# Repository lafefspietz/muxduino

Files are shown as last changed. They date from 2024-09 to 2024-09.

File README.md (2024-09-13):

# muxduino

## Arduino Shield multiplexer for audio interface to organic circuits.

This is a platform for discovering neuron-like elements in an arbitrary network of electrodes. 8 relays connect to the input side and 8 relays connect to the output side. This set of relays allows for 256x256 = 65,536 possible ways to connect the signals.  If we assume that there are neuron-like responses to be found in some combination of signal paths, we can hunt for these using software.  Algorithms can be developed to hunt for neuron-like behavior and can be improved over time.  

## [muxduino.html](muxduino.html)

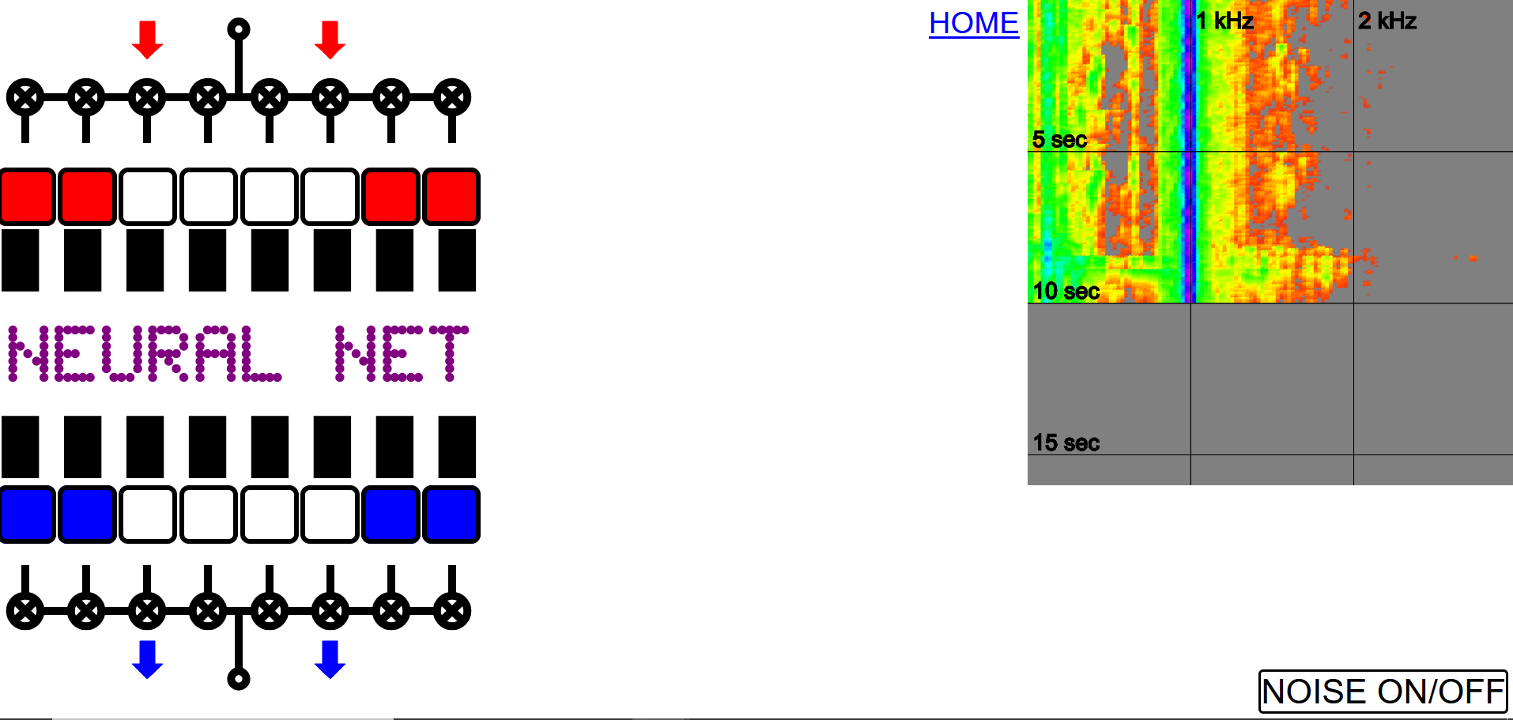
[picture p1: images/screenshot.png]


## [muxduino.py](muxduino.py)

## [arduino/muxduino/muxduino.ino](arduino/muxduino/muxduino.ino)

## [geometron/](geometron/)

## [webeditor.html](webeditor.html)

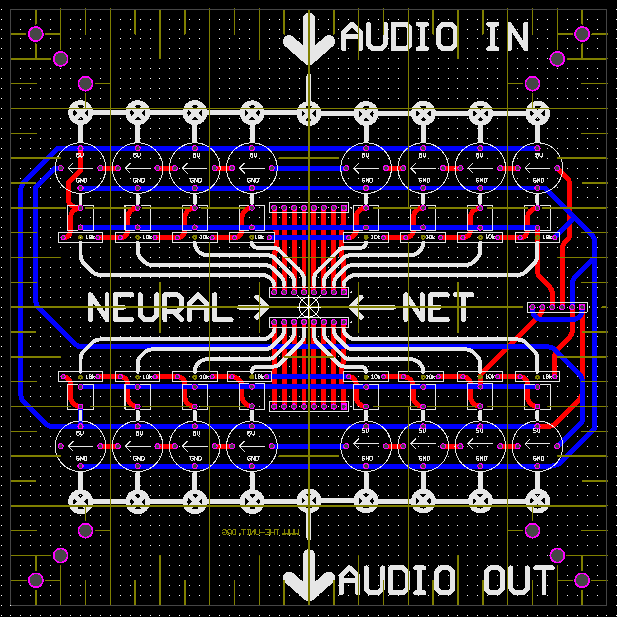
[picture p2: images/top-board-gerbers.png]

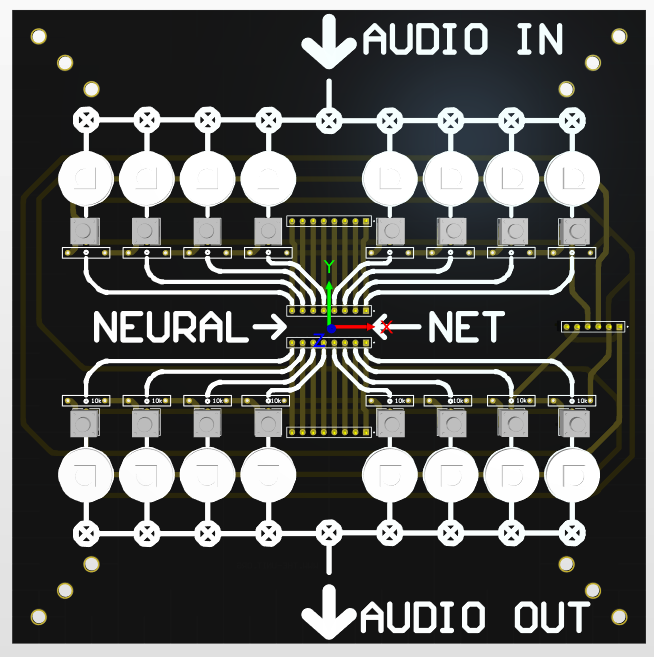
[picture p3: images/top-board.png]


 - [pcb/top-board-gerbers.zip](pcb/top-board-gerbers.zip)

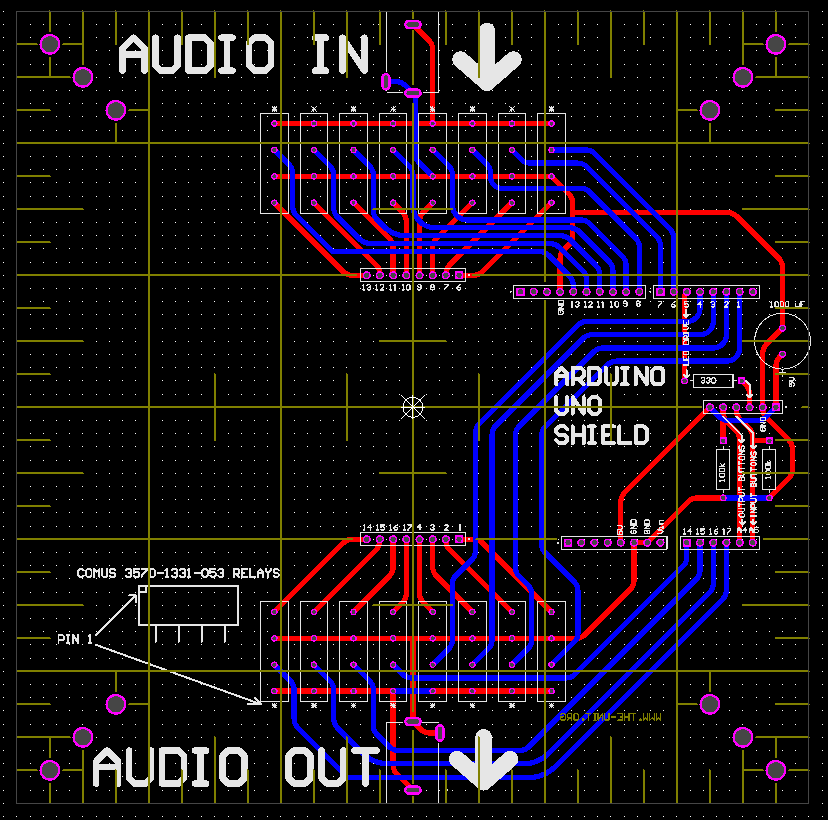
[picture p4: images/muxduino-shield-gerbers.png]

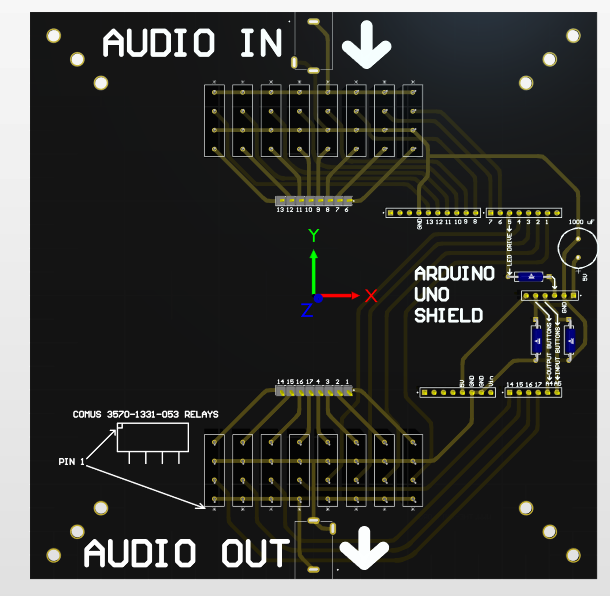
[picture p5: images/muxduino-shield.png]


 - [pcb/muxduino-shield-gerbers.zip](pcb/muxduino-shield-gerbers.zip)

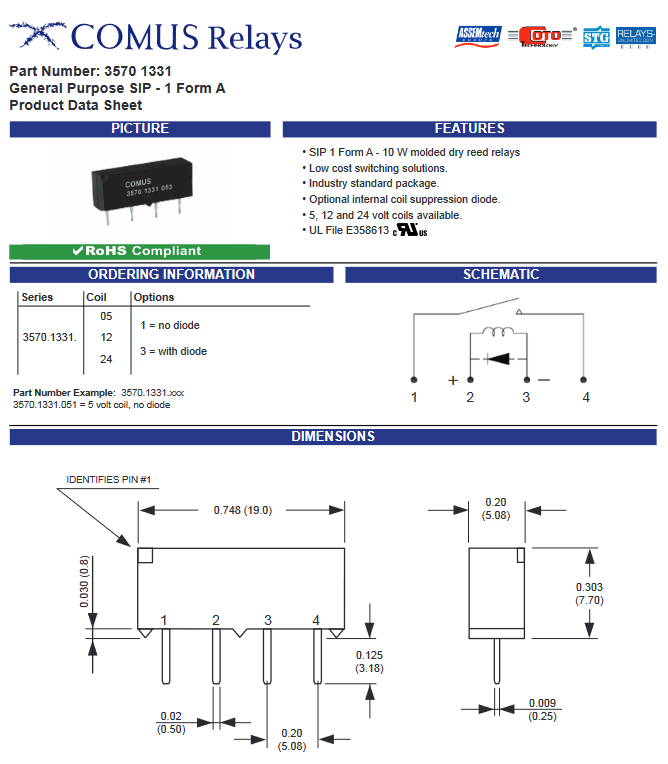
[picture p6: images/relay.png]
(https://www.digikey.com/en/products/detail/comus-international/3570-1331-053/7497099)


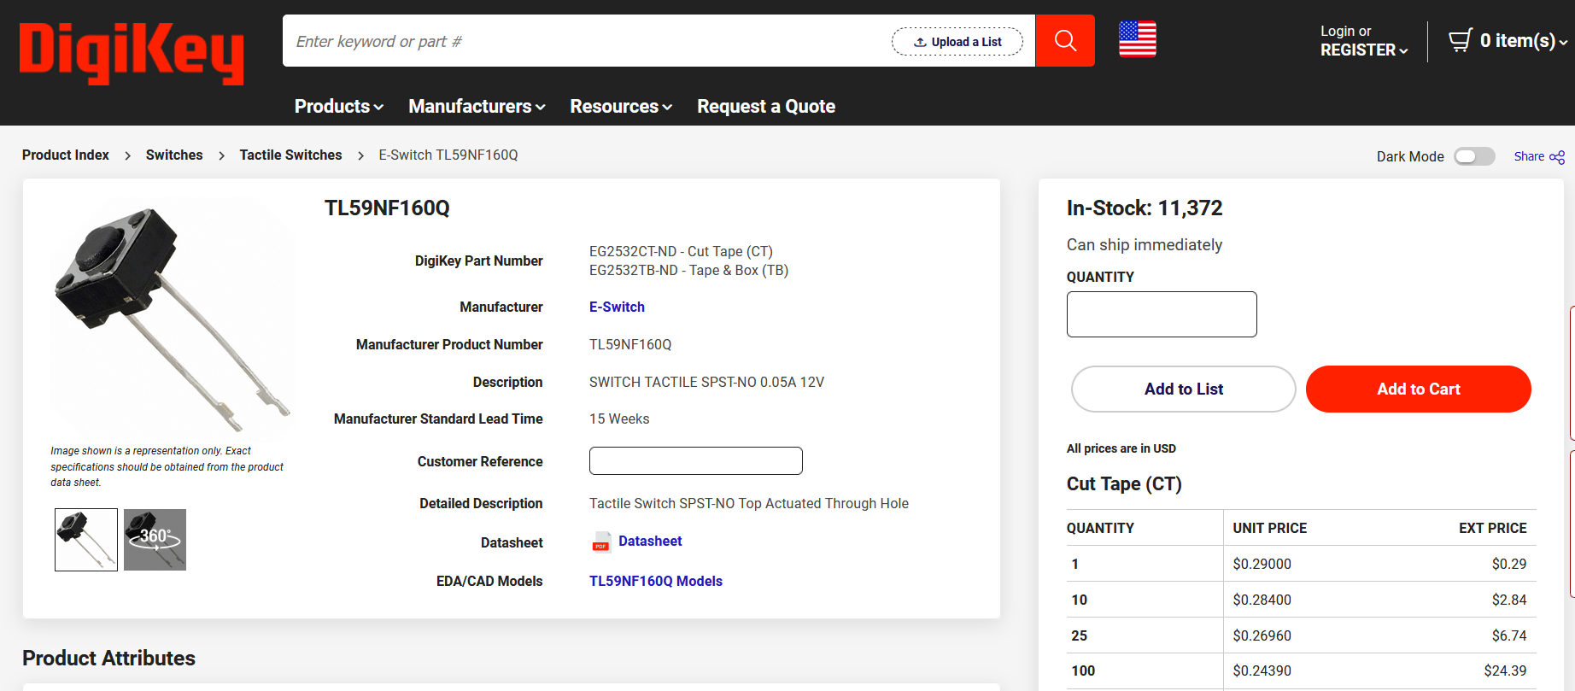
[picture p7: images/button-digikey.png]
(https://www.digikey.com/en/products/detail/e-switch/TL59NF160Q/390533)


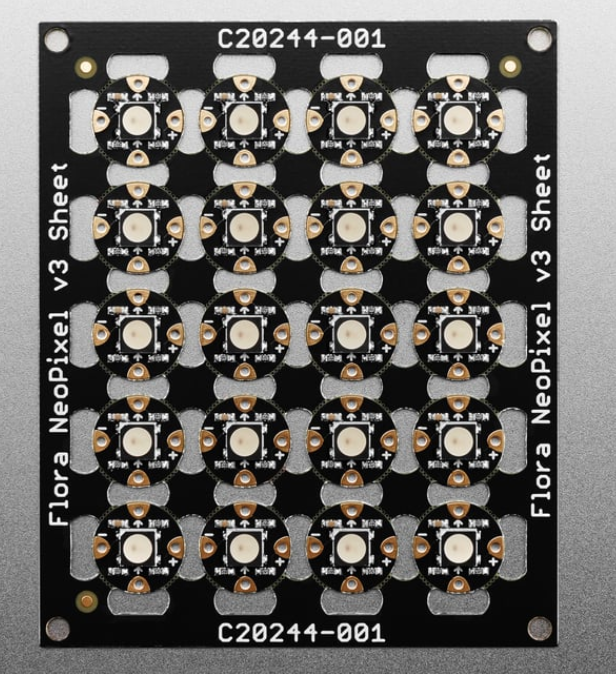
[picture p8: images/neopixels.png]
(https://www.adafruit.com/product/1559)


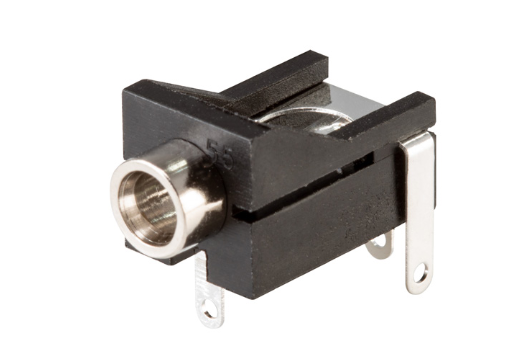
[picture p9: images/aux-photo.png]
(https://www.digikey.com/en/products/detail/cui-devices/MJ-3536N/281264)


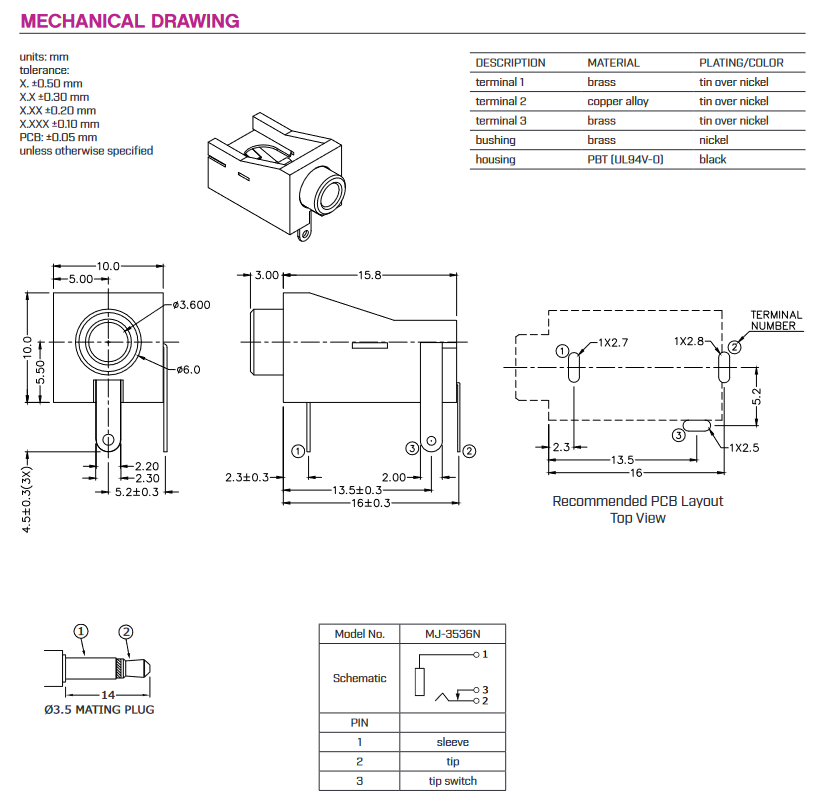
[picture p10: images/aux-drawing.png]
(https://www.digikey.com/en/products/detail/cui-devices/MJ-3536N/281264)


# Bill of Materials

 - [Comus 3570-1331-053 relay](https://www.digikey.com/en/products/detail/comus-international/3570-1331-053/7497099)
 - [Cui Devices MJ-3536N Board Mount 1/8" Audio Connector](https://www.digikey.com/en/products/detail/cui-devices/MJ-3536N/281264)
 - [E-Switch TL59NF160Q Button](https://www.digikey.com/en/products/detail/e-switch/TL59NF160Q/390533)
 - [Flora RGB Smart NeoPixel version 3 - Sheet of 20](https://www.adafruit.com/product/1559)
 - [330 ohm resistor](https://www.digikey.com/en/products/detail/stackpole-electronics-inc/CF18JT330R/1741683)
 - [100k resistor](https://www.digikey.com/en/products/detail/stackpole-electronics-inc/RNF14FTD100K/1706591)
 - [10k resistor](https://www.digikey.com/en/products/detail/yageo/MFR-25FBF52-10K/13219)
 - [1000 uF capacitor](https://www.digikey.com/en/products/detail/rubycon/16PK1000MEFC10X12-5/3563556)
 - [0.1 inch male headers](https://www.digikey.com/en/products/detail/amphenol-cs-commercial-products/G800W268018EU/17083164)
 - [6 and 8 pin socket headers](https://www.amazon.com/Didamx-120Pcs-2-54MM-Stackable-arduino/dp/B074GQ9LKY/)
 - [16 pin DIP sockets](https://www.amazon.com/uxcell-Pieces-2-54mm-Double-Adapter/dp/B00O9YPVAM/)

# CAD Files

## Libraries

 - [pcb/SchlibLafe.SchLib](pcb/SchlibLafe.SchLib)
 - [pcb/PcbLibLafe.PcbLib](pcb/PcbLibLafe.PcbLib)

## muxduino-shield

 - [pcb/muxduino-shield/muxduino-shield.PcbDoc](pcb/muxduino-shield/muxduino-shield.PcbDoc)
 - [pcb/muxduino-shield/muxduino-shield.PrjPcb](pcb/muxduino-shield/muxduino-shield.PrjPcb)
 - [pcb/muxduino-shield/muxduino-shield.PrjPcbStructure](pcb/muxduino-shield/muxduino-shield.PrjPcbStructure)
 - [pcb/muxduino-shield/muxduino-shield.SchDoc](pcb/muxduino-shield/muxduino-shield.SchDoc)
 - [pcb/muxduino-shield/muxduino-shield.step](pcb/muxduino-shield/muxduino-shield.step)

## top-board

 - [pcb/top-board/top-board.PcbDoc](pcb/top-board/top-board.PcbDoc)
 - [pcb/top-board/top-board.PrjPcb](pcb/top-board/top-board.PrjPcb)
 - [pcb/top-board/top-board.PrjPcbStructure](pcb/top-board/top-board.PrjPcbStructure)
 - [pcb/top-board/top-board.SchDoc](pcb/top-board/top-board.SchDoc)
 - [pcb/top-board/top-board.step](pcb/top-board/top-board.step)

## Switch state

The switch state is represented by an integer from 0 to 2^16-1 = 65535. This is a 16 bit number. We divide it into two bytes, the 8 bit input state and the 8 bit output state.  

## Jupyter Notebook in specific local folder

```
jupyter notebook --notebook-dir=c:\xampp\htdocs 
```

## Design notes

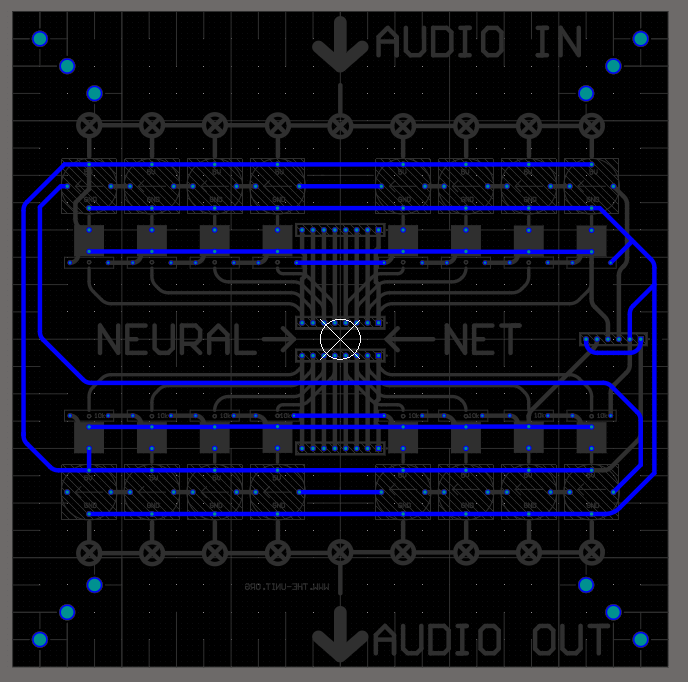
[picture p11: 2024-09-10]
images/top-board-bottom-copper.png

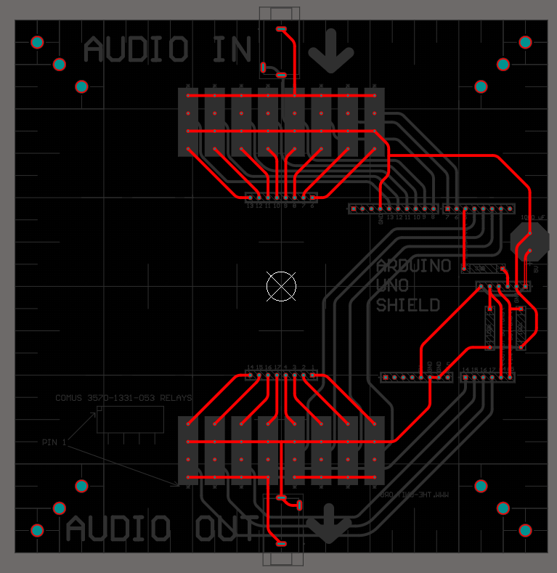
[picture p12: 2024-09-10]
images/muxduino-shield-copper.png

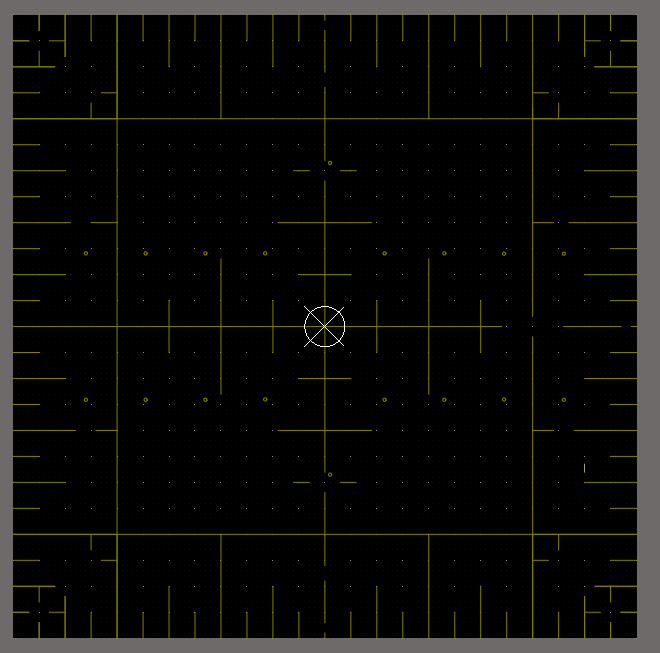
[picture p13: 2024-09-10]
images/top-board-bottom.png

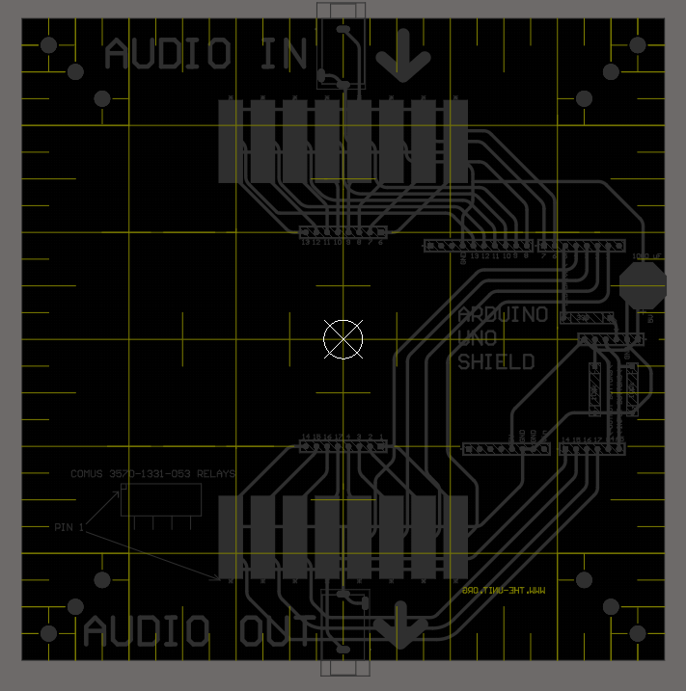
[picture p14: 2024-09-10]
images/muxduino-shield-silkscreen-bottom.png

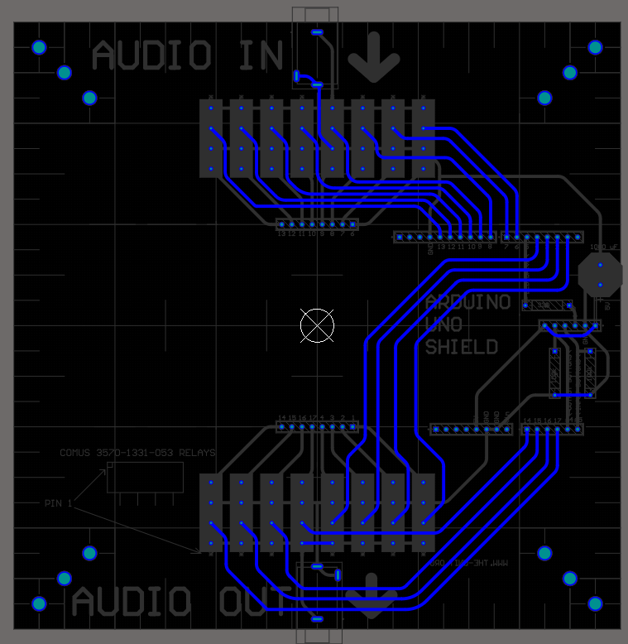
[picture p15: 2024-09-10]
images/muxduino-shield-copper-bottom.png

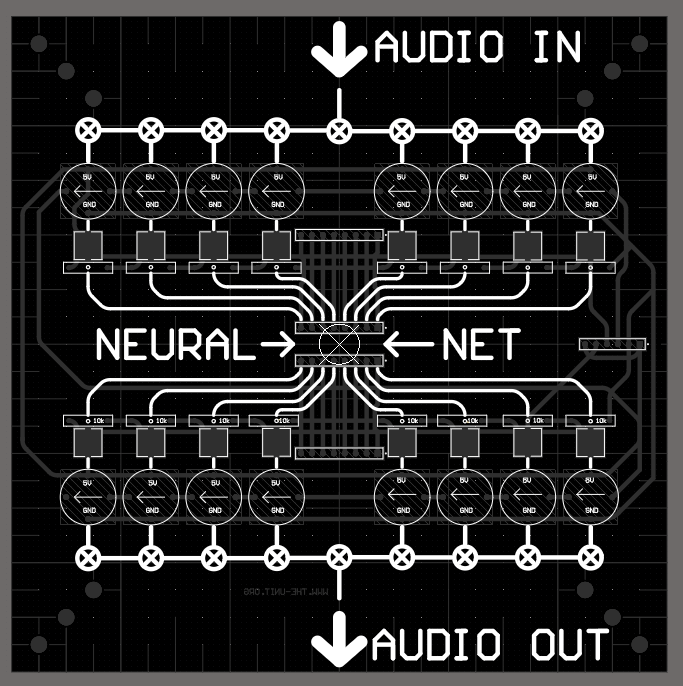
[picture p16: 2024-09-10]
images/top-board-silkscreen.png

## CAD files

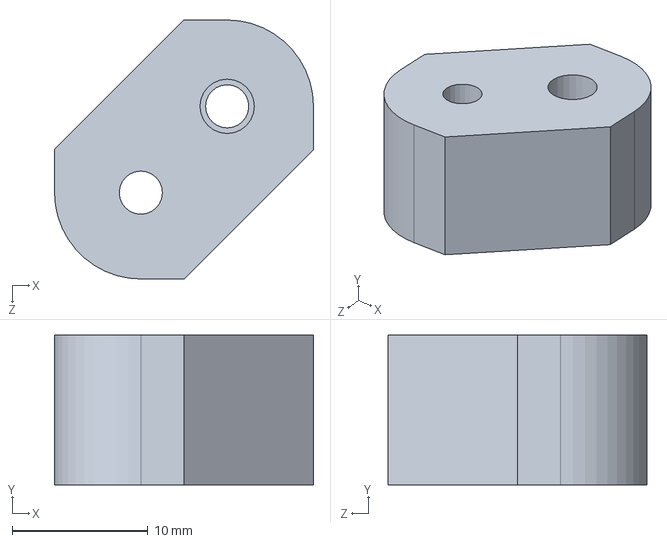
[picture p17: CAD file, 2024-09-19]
3dprint/mounting-bracket.SLDPRT
19.1 x 11.0 x 19.1 mm

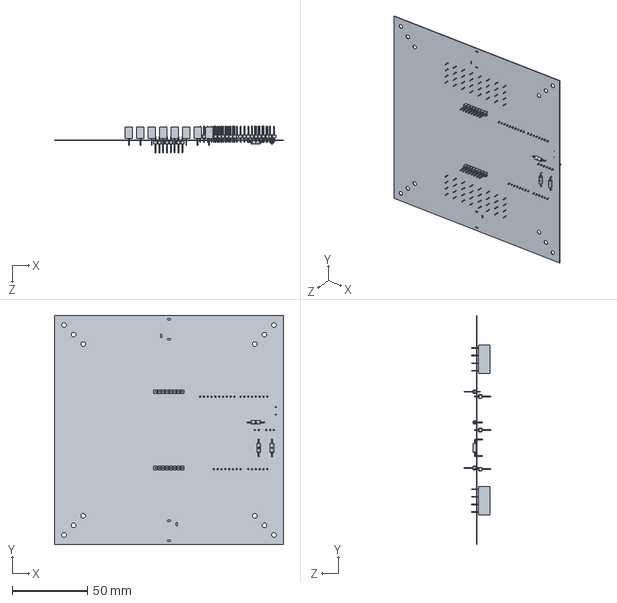
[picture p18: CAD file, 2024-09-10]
mechanical/muxduino-shield.SLDPRT
152.4 x 152.4 x 18.0 mm

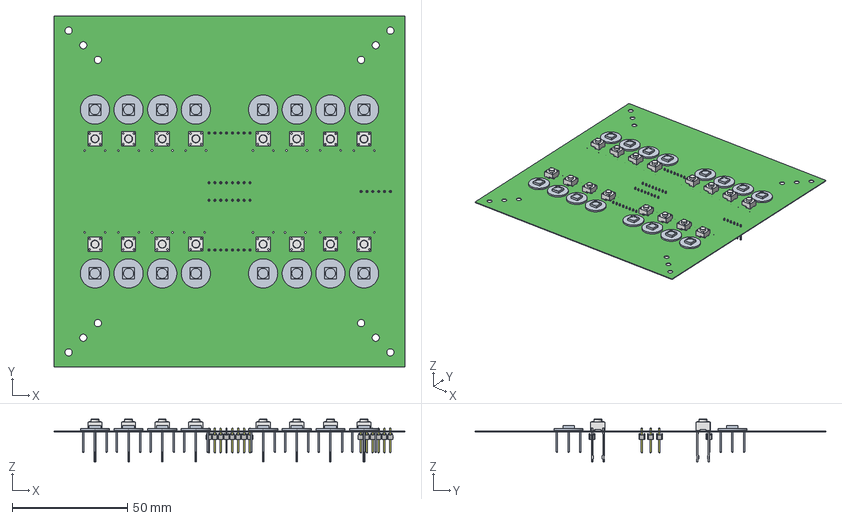
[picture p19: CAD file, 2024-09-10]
pcb/top-board/top-board.step
152.4 x 152.4 x 18.6 mm
TSW-108-07-G-S_body x 4
T-1S6-07-TSW-1-07-8-S x 4
TL59AF100Q x 16
half-inch-round-neopixel-board x 16
TSW-106-07-G-S_body
T-1S6-07-TSW-1-07-6-S

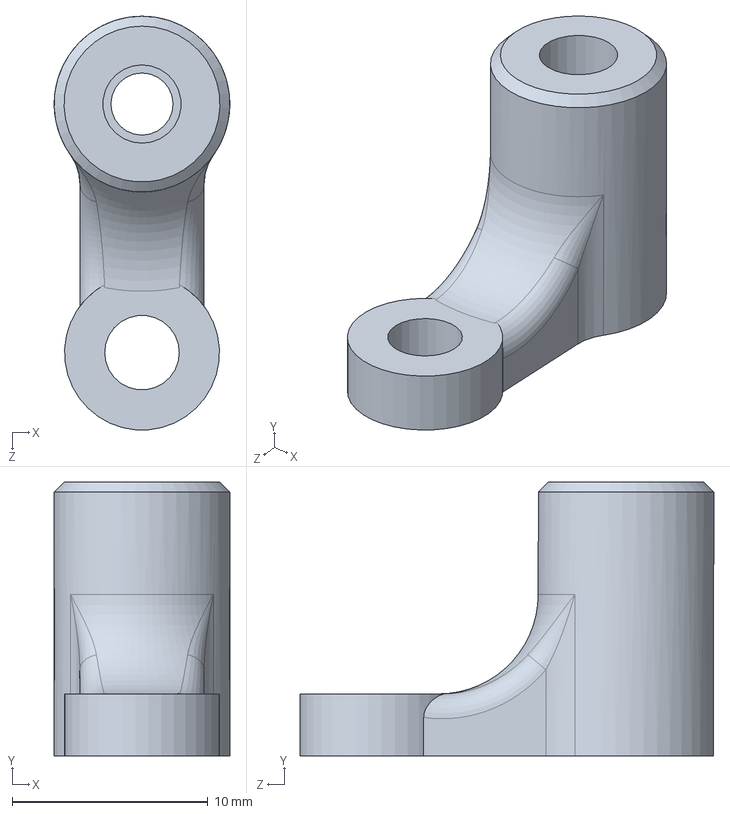
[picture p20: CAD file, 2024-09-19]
3dprint/edgebracket.SLDPRT
8.97 x 14.0 x 21.1 mm

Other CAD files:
pcb/muxduino-shield/muxduino-shield.step
3dprint/edgebracket.STL
3dprint/mounting-bracket.STL

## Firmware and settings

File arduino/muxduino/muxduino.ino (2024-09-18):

/*
*test code for building 16 bit switch controller for muxduino
*
*/

#include <Adafruit_NeoPixel.h>
#ifdef __AVR__
#endif

// Which pin on the Arduino is connected to the NeoPixels?

#define PIN 5 // UNO

// How many NeoPixels are attached to the Arduino?
#define NUMPIXELS 16 // 
//there are 16

// When setting up the NeoPixel library, we tell it how many pixels,  
// and which pin to use to send signals. Note that for older NeoPixel
// strips you might need to change the third parameter -- see the
// strandtest example for more information on possible values.
Adafruit_NeoPixel pixels(NUMPIXELS, PIN, NEO_GRB + NEO_KHZ800);


//define bit numbers on the Cryoelec controller and map them to Arduino pins

#define input1 13
#define input2 12
#define input3 11
#define input4 10
#define input5 9
#define input6 8
#define input7 7
#define input8 6

#define output1 17//this set of 4 pins{17,16,15,14} are reversed from what the silk screen says
#define output2 16
#define output3 15
#define output4 14
#define output5 4
#define output6 3
#define output7 2
#define output8 1

int inputbits[8] = {0,0,0,0,0,0,0,0};
int outputbits[8] = {0,0,0,0,0,0,0,0};

int buttonlevels[8] = {1023,823,665,536,424,321,220,114};


int inputbuttons = 0;// variable which reads out the analog input from the button ladder
int outputbuttons = 0;// variable which reads out the analog input from the button ladder
int inputbuttonsprev = 0;
int outputbuttonsprev = 0;

int delta = 20;//the acceptable difference between an analog value and an expected button state value
int mode = 1;//modes are 1,2,3,4,5,6 which are pixel 5,4,3,2,1, and 0 respectively, mode 0 is off, mode -1 is color cycle with all switches off
int cycle = 0;//variable for cycling colors as test pattern with switch off

int switchstate = 0;
String inString = "";  // string to hold input

void setup() {
    Serial.begin(9600);//set the baud rate to 9600 baud.

    //Set all bits to digital output mode:

    pinMode(input1,OUTPUT);
    pinMode(input2,OUTPUT);
    pinMode(input3,OUTPUT);
    pinMode(input4,OUTPUT);
    pinMode(input5,OUTPUT);
    pinMode(input6,OUTPUT);
    pinMode(input7,OUTPUT);
    pinMode(input8,OUTPUT);

    pinMode(output1,OUTPUT);
    pinMode(output2,OUTPUT);
    pinMode(output3,OUTPUT);
    pinMode(output4,OUTPUT);
    pinMode(output5,OUTPUT);
    pinMode(output6,OUTPUT);
    pinMode(output7,OUTPUT);
    pinMode(output8,OUTPUT);

    //set all pins low to start off with
    digitalWrite(input1,LOW);
    digitalWrite(input2,LOW);
    digitalWrite(input3,LOW);
    digitalWrite(input4,LOW);
    digitalWrite(input5,LOW);
    digitalWrite(input6,LOW);
    digitalWrite(input7,LOW);
    digitalWrite(input8,LOW);
    digitalWrite(output1,LOW);
    digitalWrite(output2,LOW);
    digitalWrite(output3,LOW);
    digitalWrite(output4,LOW);
    digitalWrite(output5,LOW);
    digitalWrite(output6,LOW);
    digitalWrite(output7,LOW);
    digitalWrite(output8,LOW);

  pixels.begin(); // INITIALIZE NeoPixel strip object (REQUIRED)

}





void loop() {


  pixels.clear(); // Set all pixel colors to 'off'

  // The first NeoPixel in a strand is #0, second is 1, all the way up
  // to the count of pixels minus one.
  
  // compare the analog value to all of the various button state values.  
  // This is a probe to see which node on a many-stage voltage divider
  //  is connected to the analog pin, which tests which button is pressed.
  // We check again after a milisecond to make sure the button state 
  // is stable and is not part of a transient signal.
  
inputbuttons = analogRead(A5);//read the analog voltage from the button ladder
outputbuttons = analogRead(A4);//read the analog voltage from the button ladder

if(inputbuttonsprev == 0){

  if(inputbuttons > buttonlevels[0] - delta){
    delay(1);
    inputbuttons = analogRead(A5);
    if(inputbuttons > buttonlevels[0] - delta){
        inputbits[0] = !inputbits[0];
    }
  }
  if(inputbuttons > buttonlevels[1] - delta && inputbuttons < buttonlevels[1] + delta){
    delay(1);
    inputbuttons = analogRead(A5);
    if(inputbuttons > buttonlevels[1] - delta && inputbuttons < buttonlevels[1] + delta){
        inputbits[1] = !inputbits[1];
    }
  }
  if(inputbuttons > buttonlevels[2] - delta && inputbuttons < buttonlevels[2] + delta){
     delay(1);
     inputbuttons = analogRead(A5);
    if(inputbuttons > buttonlevels[2] - delta && inputbuttons < buttonlevels[2] + delta){
        inputbits[2] = !inputbits[2];
    }
  }

  if(inputbuttons > buttonlevels[3] - delta && inputbuttons < buttonlevels[3] + delta){
     delay(1);
     inputbuttons = analogRead(A5);

    if(inputbuttons > buttonlevels[3] - delta && inputbuttons < buttonlevels[3] + delta){
        inputbits[3] = !inputbits[3];
    }
  }

  if(inputbuttons > buttonlevels[4] - delta && inputbuttons < buttonlevels[4] + delta){
     delay(1);
     inputbuttons = analogRead(A5);

    if(inputbuttons > buttonlevels[4] - delta && inputbuttons < buttonlevels[4] + delta){
        inputbits[4] = !inputbits[4];
    }
  }

  if(inputbuttons > buttonlevels[5] - delta && inputbuttons < buttonlevels[5] + delta){
     delay(1);
     inputbuttons = analogRead(A5);

    if(inputbuttons > buttonlevels[5] - delta && inputbuttons < buttonlevels[5] + delta){
        inputbits[5] = !inputbits[5];
    }
  }

  if(inputbuttons > buttonlevels[6] - delta && inputbuttons < buttonlevels[6] + delta){
     delay(1);
     inputbuttons = analogRead(A5);

    if(inputbuttons > buttonlevels[6] - delta && inputbuttons < buttonlevels[6] + delta){
        inputbits[6] = !inputbits[6];
    }
  }

  if(inputbuttons > buttonlevels[7] - delta && inputbuttons < buttonlevels[7] + delta){
     delay(1);
     inputbuttons = analogRead(A5);
    if(inputbuttons > buttonlevels[7] - delta && inputbuttons < buttonlevels[7] + delta){
        inputbits[7] = !inputbits[7];
    }
  }
}

if(outputbuttonsprev == 0){
  if(outputbuttons > buttonlevels[0] - delta){
    delay(1);
    outputbuttons = analogRead(A4);
    if(outputbuttons > buttonlevels[0] - delta){
        outputbits[0] = !outputbits[0];
    }
  }
  if(outputbuttons > buttonlevels[1] - delta && outputbuttons < buttonlevels[1] + delta){
    delay(1);
    outputbuttons = analogRead(A4);
    if(outputbuttons > buttonlevels[1] - delta && outputbuttons < buttonlevels[1] + delta){
        outputbits[1] = !outputbits[1];
    }
  }
  if(outputbuttons > buttonlevels[2] - delta && outputbuttons < buttonlevels[2] + delta){
     delay(1);
     outputbuttons = analogRead(A4);
    if(outputbuttons > buttonlevels[2] - delta && outputbuttons < buttonlevels[2] + delta){
        outputbits[2] = !outputbits[2];
    }
  }

  if(outputbuttons > buttonlevels[3] - delta && outputbuttons < buttonlevels[3] + delta){
     delay(1);
     outputbuttons = analogRead(A4);

    if(outputbuttons > buttonlevels[3] - delta && outputbuttons < buttonlevels[3] + delta){
        outputbits[3] = !outputbits[3];
    }
  }

  if(outputbuttons > buttonlevels[4] - delta && outputbuttons < buttonlevels[4] + delta){
     delay(1);
     outputbuttons = analogRead(A4);

    if(outputbuttons > buttonlevels[4] - delta && outputbuttons < buttonlevels[4] + delta){
        outputbits[4] = !outputbits[4];
    }
  }

  if(outputbuttons > buttonlevels[5] - delta && outputbuttons < buttonlevels[5] + delta){
     delay(1);
     outputbuttons = analogRead(A4);

    if(outputbuttons > buttonlevels[5] - delta && outputbuttons < buttonlevels[5] + delta){
        outputbits[5] = !outputbits[5];
    }
  }

  if(outputbuttons > buttonlevels[6] - delta && outputbuttons < buttonlevels[6] + delta){
     delay(1);
     outputbuttons = analogRead(A4);

    if(outputbuttons > buttonlevels[6] - delta && outputbuttons < buttonlevels[6] + delta){
        outputbits[6] = !outputbits[6];
    }
  }

  if(outputbuttons > buttonlevels[7] - delta && outputbuttons < buttonlevels[7] + delta){
     delay(1);
     outputbuttons = analogRead(A4);
    if(outputbuttons > buttonlevels[7] - delta && outputbuttons < buttonlevels[7] + delta){
        outputbits[7] = !outputbits[7];
    }
  }
}

inputbuttonsprev = inputbuttons;
outputbuttonsprev = outputbuttons;


//switchstate = 0;
 while (Serial.available() > 0) {
    int inChar = Serial.read();
    if (isDigit(inChar)) {
      // convert the incoming byte to a char and add it to the string:
      inString += (char)inChar;
    }
    // if you get a newline, print the string, then the string's value:
    if (inChar == '\n') {
      switchstate = inString.toInt();
      //Serial.println(inString);

     // Serial.println("INPUTS:");
      for(int index = 0;index < 8;index++){
        inputbits[index] = (switchstate>>(15-index))&1;       
      }
      for(int index = 0;index < 8;index++){
       // Serial.print(String(inputbits[index]));
      }
     // Serial.println();
     // Serial.println("OUTPUTS:");
      for(int index = 0;index < 8;index++){
        outputbits[index] = (switchstate>>(7 - index))&1;       
      }
      for(int index = 0;index <8;index++){
       // Serial.print(String(outputbits[index]));
      }

//      Serial.println((switchstate>>3)&1);
     // Serial.println();
      // clear the string for new input:
      inString = "";
    }
  }

  for(int index = 0;index < 8;index++){
      if(inputbits[7 - index] == 1){
          pixels.setPixelColor(index, pixels.Color(255, 0, 0));    
      } 
      else{
          pixels.setPixelColor(index, pixels.Color(0, 0, 0));    
      }   
  }
  for(int index = 0;index < 8;index++){
      if(outputbits[7 - index] == 1){
          pixels.setPixelColor(index +8, pixels.Color(0, 0, 255));    
      } 
      else{
          pixels.setPixelColor(index + 8, pixels.Color(0, 0, 0));    
      }   
  }
  pixels.show();   // Send the updated pixel colors to the hardware.

    digitalWrite(input1,inputbits[0]);
    digitalWrite(input2,inputbits[1]);
    digitalWrite(input3,inputbits[2]);
    digitalWrite(input4,inputbits[3]);
    digitalWrite(input5,inputbits[4]);
    digitalWrite(input6,inputbits[5]);
    digitalWrite(input7,inputbits[6]);
    digitalWrite(input8,inputbits[7]);
    digitalWrite(output1,outputbits[0]);
    digitalWrite(output2,outputbits[1]);
    digitalWrite(output3,outputbits[2]);
    digitalWrite(output4,outputbits[3]);
    digitalWrite(output5,outputbits[4]);
    digitalWrite(output6,outputbits[5]);
    digitalWrite(output7,outputbits[6]);
    digitalWrite(output8,outputbits[7]);

  delay(1); // Pause before next pass through loop

 
}

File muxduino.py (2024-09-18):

# open a anaconda prompt, move to c:\xampp\htdocs\muxduino and type
# python muxduino.py
import time
import serial
import os
ser = serial.Serial('COM16', 9600)
while True:
    f = open("switchstate.txt", "r")
    switchstatestring = f.read()
    ser.write(bytes(switchstatestring + '\n', encoding='utf-8'))
    f.close()
    time.sleep(0.01)

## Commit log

2024-09-09 basic structure is in place
    [8button-8eopixel.SchDoc, 8button-8neopixel.PcbDoc, CUI_MJ-3536N.PcbLib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]
2024-09-10 put it all together, this might be almost ready to order
    [muxduino-shield.PcbDoc, muxduino-shield.SchDoc, top-board.PcbDoc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]
2024-09-10 total re-arrangement of component geometry
    [muxduino-shield.PcbDoc, muxduino-shield.SchDoc, top-board.PcbDoc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]
2024-09-10 new layout mostly done
    [muxduino-shield.PcbDoc, top-board.PcbDoc]
2024-09-10 ready to ship
    [8button-8eopixel.SchDoc, 8button-8neopixel.PcbDoc, DB25-relay-HV-control.PcbDoc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]
2024-09-11 arduino code works, html code works
2024-09-12 python works, arduino works at least serial and lights
2024-09-12 fixed the python serial by removing the serial debug signals from arduino code
    [muxduino.ino]
2024-09-13 build the audio noise analyzer into the muxduino.html main page
    [muxduino.py]
2024-09-18 changed arduino code to match actual board(not random old board)
2024-09-19 3d parts
    [edgebracket.SLDPRT, edgebracket.STL, mounting-bracket.SLDPRT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]
